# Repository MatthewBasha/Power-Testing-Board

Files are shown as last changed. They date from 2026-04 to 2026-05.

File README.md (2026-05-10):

# Power Testing Board

Compact CubeSat EPS ground power-test board for ATX/boost-supplied rails.

## Current Design State

- Root KiCad project: `Power Testing board.kicad_pro`
- Schematic was regenerated first in `Power Testing board.kicad_sch`.
- Serviceable PCB placement was generated in `Power Testing board.kicad_pcb`.
- Board outline is 230 mm x 170 mm.
- PCB is routed with rail-specific copper zones, a solid B.Cu GND plane, and final JLCPCB fabrication outputs in `fabrication/JLCPCB/`.

## Electrical Architecture

Each rail follows the required order:

`RAW input -> eFuse -> INA260 VIN+ -> INA260 VIN- -> protected output distribution`

Protected outputs then split to the dedicated output terminal and the selected EPS/H1/H2 power pins. The INA260 VIN- node is the downstream positive rail, not ground.

Rails:

- `+3V3_RAW -> TPS259814L -> U5 INA260 -> +3V3_PROTECTED`
- `+5V_RAW -> TPS26631RGE -> U6 INA260 -> +5V_PROTECTED`
- `+12V_RAW -> TPS26631RGE -> U7 INA260 -> +12V_PROTECTED`
- `+16V8_RAW -> TPS26631RGE -> U8 INA260 -> +16V8_PROTECTED`

## GitHub Portability

The project includes repo-local libraries so another computer can open it after cloning:

- `Power_Testing_Board.kicad_sym`
- `Power_Testing_Board.pretty/`
- `sym-lib-table`
- `fp-lib-table`

Keep those files committed with the KiCad project. Do not rely on absolute local library paths for the custom INA260 or boost module footprints.

## Verification Notes

- ERC: 0 errors, 11 warnings. Remaining warnings are isolated optional status labels such as PG, IMON, and ALERT.
- DRC: 0 violations, 0 unconnected items after routing and zone refill.
- Gerbers/drills are generated in `fabrication/JLCPCB/` after the clean DRC gate.
- Boost footprint is based on the supplied Amazon screenshots and has been physically verified: 60 mm x 42 mm x 20 mm.
- TPS259814L footprint is marked for package/land-pattern verification against the exact ordered part.
- eFuses are on the main PCB for compactness. If repairability becomes more important than board area, move each eFuse circuit to a plug-in daughterboard.
- Passive component purposes, design checks, test point map, and assembly notes are documented in `docs/passive_component_purpose_table.md`.

## Before Ordering

- Review the Gerber ZIP and drill files in JLCPCB/JLCDFM before purchase.
- Use 2 oz copper as documented in `fabrication/JLCPCB/README_ordering.md`.
- Verify ATX, EPS/H1/H2, output terminal, boost module, INA260 module, and eFuse footprints against the physical parts.
- Select/verify the LCSC or customer-supplied plan for all SMD BOM entries before placing the PCBA order.

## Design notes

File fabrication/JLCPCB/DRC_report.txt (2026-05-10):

** Drc report for Power Testing board.kicad_pcb **
** Created on 2026-05-10T00:28:49 **
** Report includes: Errors, Warnings **

** Found 0 DRC violations **

** Found 0 unconnected pads **

** Found 0 Footprint errors **

** Ignored checks **
    - Footprint has no courtyard defined
    - Track endpoint not centered on via
    - Tuning profile track geometries
    - Footprint doesn't match symbol's footprint filters
    - Footprint component type doesn't match footprint pads

** End of Report **

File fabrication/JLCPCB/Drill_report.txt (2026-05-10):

Drill report for Power Testing board.kicad_pcb
Created on 2026-05-10T00:29:23

Copper Layer Stackup:
    =============================================================
    L1 :  F.Cu                      front
    L2 :  B.Cu                      back

Drill file 'Power Testing board.drl' contains
    plated through holes:
    =============================================================
    T1  0.200mm  0.0079"  (27 holes))
    T2  0.300mm  0.0118"  (24 holes))
    T3  0.900mm  0.0354"  (2 holes))
    T4  1.000mm  0.0394"  (166 holes))
    T5  1.100mm  0.0433"  (24 holes))
    T6  1.300mm  0.0512"  (24 holes))
    T7  1.800mm  0.0709"  (4 holes))

    Total plated holes count 271

Not plated through holes are merged with plated holes
    unplated through holes:
    =============================================================
    T8  2.500mm  0.0984"  (8 holes))
    T9  3.200mm  0.1260"  (4 holes))

    Total unplated holes count 12

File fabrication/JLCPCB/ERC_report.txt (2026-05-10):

ERC report (2026-05-10T00:28:48, Encoding UTF8)
Report includes: Errors, Warnings

***** Sheet /
[isolated_pin_label]: Label connected to only one pin
    ; warning
    @(81.28 mm, 54.61 mm): Label 'PG_3V3'
[isolated_pin_label]: Label connected to only one pin
    ; warning
    @(83.82 mm, 119.38 mm): Label 'PG_5V'
[isolated_pin_label]: Label connected to only one pin
    ; warning
    @(83.82 mm, 124.46 mm): Label 'IMON_5V'
[isolated_pin_label]: Label connected to only one pin
    ; warning
    @(138.43 mm, 69.85 mm): Label 'ALERT_3V3'
[isolated_pin_label]: Label connected to only one pin
    ; warning
    @(138.43 mm, 129.54 mm): Label 'ALERT_5V'
[isolated_pin_label]: Label connected to only one pin
    ; warning
    @(83.82 mm, 179.07 mm): Label 'PG_12V'
[isolated_pin_label]: Label connected to only one pin
    ; warning
    @(83.82 mm, 184.15 mm): Label 'IMON_12V'
[isolated_pin_label]: Label connected to only one pin
    ; warning
    @(138.43 mm, 189.23 mm): Label 'ALERT_12V'
[isolated_pin_label]: Label connected to only one pin
    ; warning
    @(83.82 mm, 240.03 mm): Label 'PG_16V8'
[isolated_pin_label]: Label connected to only one pin
    ; warning
    @(83.82 mm, 245.11 mm): Label 'IMON_16V8'
[isolated_pin_label]: Label connected to only one pin
    ; warning
    @(138.43 mm, 250.19 mm): Label 'ALERT_16V8'

 ** ERC messages: 11  Errors 0  Warnings 11

 ** Ignored checks:
    - Global label only appears once in the schematic
    - Four connection points are joined together
    - SPICE model issue
    - Assigned footprint doesn't match footprint filters

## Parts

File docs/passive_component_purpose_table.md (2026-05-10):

# Passive Component Purpose Table

Generated for the root KiCad design in `E:\Power-Testing-Board`.

## Status Summary

- Resistors in schematic: R1-R34.
- Capacitors in schematic: C1-C8.
- Current-limit target remains about 6 A, not 8 A.
- No extra main-board I2C pullups are fitted. The Adafruit INA260 Product 4226 breakouts include 10 kOhm pullups on SDA and SCL, so four installed modules make an effective pullup of about 2.5 kOhm to `+ARDUINO_5V`.
- No main-board passive parts are added at the INA260 breakout headers; the INA260 boards are treated as complete plug-in modules.
- TPS26631 `dVdT`, `MODE`, `B_GATE`, `DRV`, `PGTH`, and `IMON` support parts are not populated in this design state. `MODE` is intentionally open for latch-off behavior per the project requirement.
- TPS26631 `SHDN` is controlled only by reset button/open-drain MOSFET pulldown. Released `SHDN` is acceptable because the TPS2663 datasheet specifies an internal open-circuit SHDN voltage and a 2 V rising enable threshold.
- TPS259814L `DVDT` and `ITIMER` are intentionally open for fastest startup and fastest overcurrent response unless a delay is intentionally added later.
- TPS259814L `PG` and TPS26631 `PGOOD`/`IMON` labels remain optional one-pin status nets. `FLT` is pulled up to Arduino 5 V and routed/test-pointed.

## Calculation Notes

- TPS259814L current limit: TI gives `RILM = 6585 / ILIM`; at 6 A this is 1097.5 Ohm, so R1 = 1.10 kOhm 1%.
- TPS26631 current limit: TI electrical characteristics list RILIM = 3 kOhm for a 6 A typical overload current limit.
- UVLO/OVLO/OVP dividers use the 1.20 V typical rising threshold: `Vtrip = 1.20 V * (Rtop + Rbottom) / Rbottom`.
- TPS26631 UVLO/OVP is implemented here as two independent dividers instead of the datasheet's combined three-resistor ladder. The threshold equation is the same comparator ratio form; the divider currents remain well above pin leakage.
- MOSFET gate resistors are engineering-standard damping/current-limiting values. Gate pulldowns are engineering-standard fail-off bias values.
- eFuse capacitor values are explicitly accepted starting values, not load-transient calculations. They satisfy local bypass intent, but final transient/load validation should confirm whether larger bulk capacitance or TVS/Schottky protection is needed.

## Capacitors

| Ref | Value | Footprint/package | Connected nets | Supports | Purpose | Required / optional / DNP | Datasheet section or design reason | Value source |
|---|---:|---|---|---|---|---|---|---|
| C1 | 1 uF 25 V X7R | C_0805_2012Metric | `+3V3_RAW` to `GND` | U1 TPS259814L | Local input bypass at 3.3 V eFuse input. | Required | TPS25981 power-supply/transient guidance: local input ceramic bypass close to IN/GND. | Accepted starting value; voltage rating selected with margin. |
| C2 | 10 uF 25 V X7R | C_0805_2012Metric | `+3V3_EFUSE_OUT` to `GND` | U1 TPS259814L and U5 INA260 input side | Local OUT-side capacitance before the INA260 module. | Required | TPS25981 transient guidance calls for low-ESR capacitance close to OUT/GND for output transients. | Accepted starting value; verify with load transient testing. |
| C3 | 1 uF 25 V X7R | C_0805_2012Metric | `+5V_RAW` to `GND` | U2 TPS26631 | Local input bypass at 5 V eFuse input. | Required | TPS2663 recommends at least 0.1 uF IN_SYS-GND decoupling and at least 1 uF input capacitance for transient-prone applications. | Copied/accepted from TI guidance. |
| C4 | 10 uF 25 V X7R | C_0805_2012Metric | `+5V_EFUSE_OUT` to `GND` | U2 TPS26631 and U6 INA260 input side | Local OUT-side/load-side capacitance before the INA260 module. | Required | TPS2663 application figures include output capacitance; exact value depends on load/inrush. | Accepted starting value; verify inrush/transient behavior. |
| C5 | 1 uF 50 V X7R | C_0805_2012Metric | `+12V_RAW` to `GND` | U3 TPS26631 | Local input bypass at 12 V eFuse input. | Required | TPS2663 decoupling/transient guidance. | Copied/accepted from TI guidance; 50 V rating for derating. |
| C6 | 10 uF 50 V X7R | C_0805_2012Metric | `+12V_EFUSE_OUT` to `GND` | U3 TPS26631 and U7 INA260 input side | Local OUT-side/load-side capacitance before the INA260 module. | Required | TPS2663 application/output capacitance guidance. | Accepted starting value; verify inrush/transient behavior. |
| C7 | 1 uF 50 V X7R | C_0805_2012Metric | `+16V8_RAW` to `GND` | U4 TPS26631 | Local input bypass at 16.8 V eFuse input. | Required | TPS2663 decoupling/transient guidance. | Copied/accepted from TI guidance; 50 V rating for derating. |
| C8 | 10 uF 50 V X7R | C_0805_2012Metric | `+16V8_EFUSE_OUT` to `GND` | U4 TPS26631 and U8 INA260 input side | Local OUT-side/load-side capacitance before the INA260 module. | Required | TPS2663 application/output capacitance guidance. | Accepted starting value; verify inrush/transient behavior. |

## Resistors

| Ref | Value | Footprint/package | Connected nets | Supports | Purpose | Required / optional / DNP | Datasheet section or design reason | Value source |
|---|---:|---|---|---|---|---|---|---|
| R1 | 1.10 kOhm 1% | R_0805_2012Metric | `ILIM_3V3` to `GND` | U1 TPS259814L | Sets 3.3 V eFuse current limit near 6 A. | Required | TPS25981 ILM equation `RILM = 6585 / ILIM`. | Calculated: 6585 / 6 A = 1097.5 Ohm. |
| R2 | 100 kOhm 1% | R_0603_1608Metric | `+3V3_RAW` to `RESET_3V3` | U1 EN/UVLO | Top of EN/UVLO divider; normally enables U1. | Required | TPS25981 EN/UVLO divider equation. | Calculated/selected: with R3 gives 2.40 V rising UVLO. |
| R3 | 100 kOhm 1% | R_0603_1608Metric | `RESET_3V3` to `GND` | U1 EN/UVLO | Bottom of EN/UVLO divider and reset node bias. | Required | TPS25981 EN/UVLO divider equation. | Calculated/selected with R2. |
| R4 | 24.9 kOhm 1% | R_0603_1608Metric | `+3V3_RAW` to `OVLO_3V3` | U1 EN/OVLO | Top of 3.3 V OVLO divider. | Required | TPS25981 EN/OVLO divider equation. | Calculated: with R5 gives 4.19 V rising OVLO. |
| R5 | 10 kOhm 1% | R_0603_1608Metric | `OVLO_3V3` to `GND` | U1 EN/OVLO | Bottom of 3.3 V OVLO divider. | Required | TPS25981 EN/OVLO divider equation. | Calculated/selected with R4. |
| R6 | 330 Ohm | R_0603_1608Metric | `ARD_RESET_3V3` to `GATE_3V3` | Q1 / U1 reset | Arduino GPIO series gate resistor. | Required if Arduino reset is populated | Limits instantaneous GPIO/gate current and damps ringing. | Justified engineering-standard value. |
| R7 | 100 kOhm | R_0603_1608Metric | `GATE_3V3` to `GND` | Q1 / U1 reset | Holds reset MOSFET off while Arduino resets/unpowered. | Required | Fail-off MOSFET gate bias. | Justified engineering-standard value. |
| R8 | 10 kOhm | R_0603_1608Metric | `FLT_3V3` to `+ARDUINO_5V` | U1 FLT | Pulls open-drain fault output to Arduino logic. | Required if FLT is used; DNP if unused | TPS25981 FLT is open-drain; 10 kOhm gives about 0.5 mA sink at 5 V. | Justified/calculated pullup value. |
| R9 | 3.00 kOhm 1% | R_0805_2012Metric | `ILIM_5V` to `GND` | U2 TPS26631 | Sets 5 V current limit near 6 A. | Required | TPS2663 current-limit table: 3 kOhm gives 6 A typical. | Copied from datasheet/user requirement. |
| R10 | 261 kOhm 1% | R_0603_1608Metric | `+5V_RAW` to `UVLO_5V` | U2 UVLO | Top of 5 V UVLO divider. | Required | TPS2663 UVLO threshold 1.20 V typical. | Calculated: with R11 gives 4.33 V rising UVLO. |
| R11 | 100 kOhm 1% | R_0603_1608Metric | `UVLO_5V` to `GND` | U2 UVLO | Bottom of 5 V UVLO divider. | Required | TPS2663 UVLO divider design. | Calculated/selected with R10. |
| R12 | 383 kOhm 1% | R_0603_1608Metric | `+5V_RAW` to `OVP_5V` | U2 OVP | Top of 5 V OVP divider. | Required | TPS2663 OVP threshold 1.20 V typical. | Calculated: with R13 gives 5.80 V rising OVP. |
| R13 | 100 kOhm 1% | R_0603_1608Metric | `OVP_5V` to `GND` | U2 OVP | Bottom of 5 V OVP divider. | Required | TPS2663 OVP divider design. | Calculated/selected with R12. |
| R14 | 330 Ohm | R_0603_1608Metric | `ARD_RESET_5V` to `GATE_5V` | Q2 / U2 SHDN | Arduino GPIO series gate resistor. | Required if Arduino reset is populated | GPIO/gate damping and current limiting. | Justified engineering-standard value. |
| R15 | 100 kOhm | R_0603_1608Metric | `GATE_5V` to `GND` | Q2 / U2 SHDN | Holds reset MOSFET off while Arduino resets/unpowered. | Required | Fail-off MOSFET gate bias. | Justified engineering-standard value. |
| R16 | 10 kOhm | R_0603_1608Metric | `FLT_5V` to `+ARDUINO_5V` | U2 FLT | Pulls open-drain fault output to Arduino logic. | Required if FLT is used; DNP if unused | TPS2663 FLT is open-drain and may be left open if unused. | Justified/calculated: about 0.5 mA when asserted. |
| R17 | 3.00 kOhm 1% | R_0805_2012Metric | `ILIM_12V` to `GND` | U3 TPS26631 | Sets 12 V current limit near 6 A. | Required | TPS2663 current-limit table. | Copied from datasheet/user requirement. |
| R18 | 806 kOhm 1% | R_0603_1608Metric | `+12V_RAW` to `UVLO_12V` | U3 UVLO | Top of 12 V UVLO divider. | Required | TPS2663 UVLO threshold 1.20 V typical. | Calculated: with R19 gives 10.87 V rising UVLO. |
| R19 | 100 kOhm 1% | R_0603_1608Metric | `UVLO_12V` to `GND` | U3 UVLO | Bottom of 12 V UVLO divider. | Required | TPS2663 UVLO divider design. | Calculated/selected with R18. |
| R20 | 1.05 MOhm 1% | R_0603_1608Metric | `+12V_RAW` to `OVP_12V` | U3 OVP | Top of 12 V OVP divider. | Required | TPS2663 OVP threshold 1.20 V typical. | Calculated: with R21 gives 13.80 V rising OVP. |
| R21 | 100 kOhm 1% | R_0603_1608Metric | `OVP_12V` to `GND` | U3 OVP | Bottom of 12 V OVP divider. | Required | TPS2663 OVP divider design. | Calculated/selected with R20. |
| R22 | 330 Ohm | R_0603_1608Metric | `ARD_RESET_12V` to `GATE_12V` | Q3 / U3 SHDN | Arduino GPIO series gate resistor. | Required if Arduino reset is populated | GPIO/gate damping and current limiting. | Justified engineering-standard value. |
| R23 | 100 kOhm | R_0603_1608Metric | `GATE_12V` to `GND` | Q3 / U3 SHDN | Holds reset MOSFET off while Arduino resets/unpowered. | Required | Fail-off MOSFET gate bias. | Justified engineering-standard value. |
| R24 | 10 kOhm | R_0603_1608Metric | `FLT_12V` to `+ARDUINO_5V` | U3 FLT | Pulls open-drain fault output to Arduino logic. | Required if FLT is used; DNP if unused | TPS2663 FLT open-drain use. | Justified/calculated: about 0.5 mA when asserted. |
| R25 | 3.00 kOhm 1% | R_0805_2012Metric | `ILIM_16V8` to `GND` | U4 TPS26631 | Sets 16.8 V current limit near 6 A. | Required | TPS2663 current-limit table. | Copied from datasheet/user requirement. |
| R26 | 1.07 MOhm 1% | R_0603_1608Metric | `+16V8_RAW` to `UVLO_16V8` | U4 UVLO | Top of 16.8 V UVLO divider. | Required | TPS2663 UVLO threshold 1.20 V typical. | Calculated: with R27 gives 14.04 V rising UVLO. |
| R27 | 100 kOhm 1% | R_0603_1608Metric | `UVLO_16V8` to `GND` | U4 UVLO | Bottom of 16.8 V UVLO divider. | Required | TPS2663 UVLO divider design. | Calculated/selected with R26. |
| R28 | 1.40 MOhm 1% | R_0603_1608Metric | `+16V8_RAW` to `OVP_16V8` | U4 OVP | Top of 16.8 V OVP divider. | Required | TPS2663 OVP threshold 1.20 V typical. | Calculated: with R29 gives 18.00 V rising OVP. |
| R29 | 100 kOhm 1% | R_0603_1608Metric | `OVP_16V8` to `GND` | U4 OVP | Bottom of 16.8 V OVP divider. | Required | TPS2663 OVP divider design. | Calculated/selected with R28. |
| R30 | 330 Ohm | R_0603_1608Metric | `ARD_RESET_16V8` to `GATE_16V8` | Q4 / U4 SHDN | Arduino GPIO series gate resistor. | Required if Arduino reset is populated | GPIO/gate damping and current limiting. | Justified engineering-standard value. |
| R31 | 100 kOhm | R_0603_1608Metric | `GATE_16V8` to `GND` | Q4 / U4 SHDN | Holds reset MOSFET off while Arduino resets/unpowered. | Required | Fail-off MOSFET gate bias. | Justified engineering-standard value. |
| R32 | 10 kOhm | R_0603_1608Metric | `FLT_16V8` to `+ARDUINO_5V` | U4 FLT | Pulls open-drain fault output to Arduino logic. | Required if FLT is used; DNP if unused | TPS2663 FLT open-drain use. | Justified/calculated: about 0.5 mA when asserted. |
| R33 | 330 Ohm | R_0603_1608Metric | `ATX_PS_ON_CTL` to `GATE_PS_ON` | Q5 ATX PS_ON# | Arduino GPIO series gate resistor. | Required if Arduino PS_ON control is populated | GPIO/gate damping and current limiting. | Justified engineering-standard value. |
| R34 | 100 kOhm | R_0603_1608Metric | `GATE_PS_ON` to `GND` | Q5 ATX PS_ON# | Holds ATX PS_ON MOSFET off while Arduino resets/unpowered. | Required | Fail-off MOSFET gate bias. | Justified engineering-standard value. |

## Design Checks Before Routing/Fabrication

| Check | Result |
|---|---|
| Rail order on every rail | Confirmed in schematic/PCB net assignment: RAW -> eFuse -> INA260 VIN+ -> INA260 VIN- -> protected node. |
| eFuse before INA260 | Confirmed for +3.3 V, +5 V, +12 V, and +16.8 V. |
| INA260 measures protected load power | Confirmed: dedicated outputs and EPS/header pins use only the `+RAIL_PROTECTED` nets after INA260 VIN-. |
| INA260 VIN- never tied to GND | Confirmed: U5-U8 pad 8 nets are `+3V3_PROTECTED`, `+5V_PROTECTED`, `+12V_PROTECTED`, and `+16V8_PROTECTED`. |
| Dedicated output and EPS/header included in measurement | Confirmed: J4 and H1/H2 selected power pins branch from protected post-INA260 nets. |
| Common ground | Confirmed by shared `GND` net for ATX, Arduino, INA260 modules, eFuses, boost module, and outputs. |
| Current-limit target | Confirmed near 6 A by R1/R9/R17/R25; board copper/connectors still need 8 A to 10 A routing margin. |
| ATX input connector style | Confirmed screw terminals J1/J2, not a 24-pin ATX motherboard connector. |
| ATX PS_ON# control | Confirmed: green-wire `ATX_PS_ON_N` enters J2, external switch J3 shorts it to GND, Arduino pulls low through Q5 only. |
| Reset buttons | Confirmed SW1-SW4 are momentary through-hole buttons on an edge row, pulling each reset/control node low. |
| Arduino Nano orientation | Confirmed: A1 uses `Module:Arduino_Nano`, is header-mounted, rotated 90 degrees; USB is intended to face the left board edge. |
| Modularity | Confirmed for Arduino headers, INA260 module headers, verified boost module footprint, ATX terminals, output terminals, EPS headers, and through-hole buttons. |
| SMD eFuse serviceability | Manufacturer-assembled SMD; placed on main PCB with nearby passives/test points, not hidden under plug-in modules. |
| High-current layout | Not complete. Must be routed with wide pours/traces, 2 oz copper preferred, via arrays for layer changes, solid GND plane, short eFuse-to-INA260 current path, and thermal via stitching. |
| Test points | Confirmed TP1-TP29 cover requested rail states, GND, I2C, ATX control/status, reset, FLT, and boost input/output/GND. |
| Connector footprints | Present for ATX screw terminals, verified boost module, Adafruit INA260 modules, Arduino Nano, dedicated outputs, H1/H2 EPS headers, and reset buttons. Final physical current-rating review still required. |

## Test Point Map

| Net/function | Test point |
|---|---|
| `+3V3_RAW` | TP1 |
| `+3V3_EFUSE_OUT` | TP2 |
| `+3V3_PROTECTED` | TP3 |
| `+5V_RAW` | TP4 |
| `+5V_EFUSE_OUT` | TP5 |
| `+5V_PROTECTED` | TP6 |
| `+12V_RAW` | TP7 |
| `+12V_EFUSE_OUT` | TP8 |
| `+12V_PROTECTED` | TP9 |
| `+16V8_RAW` | TP10 |
| `+16V8_EFUSE_OUT` | TP11 |
| `+16V8_PROTECTED` | TP12 |
| `GND` | TP13 |
| `I2C_SDA` | TP14 |
| `I2C_SCL` | TP15 |
| `ATX_PS_ON_N` | TP16 |
| `ATX_PWR_OK` | TP17 |
| `+5VSB` | TP18 |
| `RESET_3V3` | TP19 |
| `RESET_5V` | TP20 |
| `RESET_12V` | TP21 |
| `RESET_16V8` | TP22 |
| `FLT_3V3` | TP23 |
| `FLT_5V` | TP24 |
| `FLT_12V` | TP25 |
| `FLT_16V8` | TP26 |
| `BOOST_IN+` / `+12V_RAW` | TP27 |
| `BOOST_OUT+` / `+16V8_RAW` | TP28 |
| `BOOST_GND` | TP29 |

## Current ERC/DRC Status

- ERC: 0 errors, 11 warnings. Warnings are isolated optional labels for PG, IMON, and ALERT signals.
- DRC: 0 violations, 0 unconnected items after routing and copper-zone refill.
- Routing gate: passed. Final Gerbers/drills were generated after the clean DRC gate.

## Source References

- TI TPS2663 datasheet/product page: https://www.ti.com/lit/gpn/TPS2663
- TI TPS25981 datasheet: https://www.ti.com/lit/ds/symlink/tps25981.pdf
- Adafruit INA260 Product 4226: https://www.adafruit.com/product/4226
- Adafruit INA260 pinouts and onboard I2C pullups: https://learn.adafruit.com/adafruit-ina260-current-voltage-power-sensor-breakout/pinouts

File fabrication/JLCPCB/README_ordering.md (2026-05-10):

# JLCPCB Ordering README

Status: ready for fabrication-file review.

## Current gate

- Gerber ZIP: generated after DRC clean.
- Drill files: generated after DRC clean.
- KiCad DRC: 0 violations, 0 unconnected items.
- Use JLCPCB/JLCDFM preview to verify board outline, drills, solder mask, and assembly rotations before purchase.

## Recommended order settings after DRC is clean

- PCB type: FR-4, 2 layers unless routing requires a 4-layer revision.
- Board thickness: 1.6 mm.
- Copper weight: 2 oz outer copper preferred for high-current margin. Confirm current availability/pricing on the JLCPCB order page.
- Solder mask: green preferred for lowest process risk unless the team wants a different color.
- Surface finish: ENIG preferred for the fine-pitch QFN/eFuse footprints and flatter pads; lead-free HASL is acceptable only after confirming pad planarity/rework tradeoffs.
- Assembly side: top side only for the SMD manufacturer-assembled parts.
- Manual parts: exclude headers, modules, screw terminals, EPS connectors, and reset buttons from the JLCPCB SMD BOM/CPL unless the team explicitly decides otherwise.

## JLCPCB file-prep reminders

- BOM and CPL designators must match exactly.
- Use millimeters in the CPL.
- Check every SMD rotation in JLCPCB preview, especially U1-U4 and Q1-Q5.
- Replace all `CUSTOMER_SUPPLIED_OR_SELECT_LCSC` / `CUSTOMER_SUPPLIED_OR_VERIFY_LCSC` placeholders with real selected parts or a JLCPCB customer-supplied-parts plan before ordering.

Sources checked:

- JLCPCB copper weight guide: https://jlcpcb.com/help/article/jlcpcb-copper-weight
- JLCPCB surface finish guide: https://jlcpcb.com/help/article/jlcpcb-surface-finish
- JLCPCB BOM/CPL preparation guidance: https://jlcpcb.com/help/article/advice-for-bom-and-cpl-files-preparation

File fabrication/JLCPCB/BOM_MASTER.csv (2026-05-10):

Designator | Value | Footprint | Category | Install responsibility | LCSC Part # | Manufacturer Part # / Notes
A1 | Arduino Nano USB-powered socket | Arduino_Nano | Manual/serviceable | Install manually after PCBA | N/A | Arduino Nano USB-powered socket
C1 | 1uF 25V X7R input close to eFuse | C_0805_2012Metric | SMD manufacturer-assembled | JLCPCB | CUSTOMER_SUPPLIED_OR_SELECT_LCSC | Generic passive; select voltage/tolerance/package in JLC parts library
C2 | 10uF 25V X7R output close to eFuse | C_0805_2012Metric | SMD manufacturer-assembled | JLCPCB | CUSTOMER_SUPPLIED_OR_SELECT_LCSC | Generic passive; select voltage/tolerance/package in JLC parts library
C3 | 1uF 25V X7R input close to eFuse | C_0805_2012Metric | SMD manufacturer-assembled | JLCPCB | CUSTOMER_SUPPLIED_OR_SELECT_LCSC | Generic passive; select voltage/tolerance/package in JLC parts library
C4 | 10uF 25V X7R output close to eFuse | C_0805_2012Metric | SMD manufacturer-assembled | JLCPCB | CUSTOMER_SUPPLIED_OR_SELECT_LCSC | Generic passive; select voltage/tolerance/package in JLC parts library
C5 | 1uF 50V X7R input close to eFuse | C_0805_2012Metric | SMD manufacturer-assembled | JLCPCB | CUSTOMER_SUPPLIED_OR_SELECT_LCSC | Generic passive; select voltage/tolerance/package in JLC parts library
C6 | 10uF 50V X7R output close to eFuse | C_0805_2012Metric | SMD manufacturer-assembled | JLCPCB | CUSTOMER_SUPPLIED_OR_SELECT_LCSC | Generic passive; select voltage/tolerance/package in JLC parts library
C7 | 1uF 50V X7R input close to eFuse | C_0805_2012Metric | SMD manufacturer-assembled | JLCPCB | CUSTOMER_SUPPLIED_OR_SELECT_LCSC | Generic passive; select voltage/tolerance/package in JLC parts library
C8 | 10uF 50V X7R output close to eFuse | C_0805_2012Metric | SMD manufacturer-assembled | JLCPCB | CUSTOMER_SUPPLIED_OR_SELECT_LCSC | Generic passive; select voltage/tolerance/package in JLC parts library
J1 | J_ATX_PWR: 3V3 3V3 5V 5V 12V 12V GNDx4 | TerminalBlock_MaiXu_MX126-5.0-10P_1x10_P5.00mm | Manual/serviceable | Install manually after PCBA | N/A | J_ATX_PWR: 3V3 3V3 5V 5V 12V 12V GNDx4
J2 | J_ATX_CTRL: PS_ON PWR_OK 5VSB GND | TerminalBlock_MaiXu_MX126-5.0-04P_1x04_P5.00mm | Manual/serviceable | Install manually after PCBA | N/A | J_ATX_CTRL: PS_ON PWR_OK 5VSB GND
J3 | ATX_SWITCH | TerminalBlock_MaiXu_MX126-5.0-02P_1x02_P5.00mm | Manual/serviceable | Install manually after PCBA | N/A | ATX_SWITCH
J4 | DEDICATED OUTPUTS: 3V3/G 5V/G 12V/G 16V8/G | TerminalBlock_MaiXu_MX126-5.0-08P_1x08_P5.00mm | Manual/serviceable | Install manually after PCBA | N/A | DEDICATED OUTPUTS: 3V3/G 5V/G 12V/G 16V8/G
JH1 | H1 selected power/GND pins only | PinSocket_2x26_P2.54mm_Vertical | Manual/serviceable | Install manually after PCBA | N/A | H1 selected power/GND pins only
JH2 | H2 selected power/GND pins only | PinSocket_2x26_P2.54mm_Vertical | Manual/serviceable | Install manually after PCBA | N/A | H2 selected power/GND pins only
Q1 | 2N7002 RESET_3V3 pulldown | SOT-23 | SMD manufacturer-assembled | JLCPCB | CUSTOMER_SUPPLIED_OR_SELECT_LCSC | 2N7002 SOT-23, select JLC basic/extended part before order
Q2 | 2N7002 RESET_5V pulldown | SOT-23 | SMD manufacturer-assembled | JLCPCB | CUSTOMER_SUPPLIED_OR_SELECT_LCSC | 2N7002 SOT-23, select JLC basic/extended part before order
Q3 | 2N7002 RESET_12V pulldown | SOT-23 | SMD manufacturer-assembled | JLCPCB | CUSTOMER_SUPPLIED_OR_SELECT_LCSC | 2N7002 SOT-23, select JLC basic/extended part before order
Q4 | 2N7002 RESET_16V8 pulldown | SOT-23 | SMD manufacturer-assembled | JLCPCB | CUSTOMER_SUPPLIED_OR_SELECT_LCSC | 2N7002 SOT-23, select JLC basic/extended part before order
Q5 | 2N7002 ATX PS_ON# pulldown | SOT-23 | SMD manufacturer-assembled | JLCPCB | CUSTOMER_SUPPLIED_OR_SELECT_LCSC | 2N7002 SOT-23, select JLC basic/extended part before order
R1 | 1.10k 1% ILM ~6A | R_0805_2012Metric | SMD manufacturer-assembled | JLCPCB | CUSTOMER_SUPPLIED_OR_SELECT_LCSC | Generic passive; select voltage/tolerance/package in JLC parts library
R2 | 100k 1% EN top 2.40V | R_0603_1608Metric | SMD manufacturer-assembled | JLCPCB | CUSTOMER_SUPPLIED_OR_SELECT_LCSC | Generic passive; select voltage/tolerance/package in JLC parts library
R3 | 100k 1% EN bottom | R_0603_1608Metric | SMD manufacturer-assembled | JLCPCB | CUSTOMER_SUPPLIED_OR_SELECT_LCSC | Generic passive; select voltage/tolerance/package in JLC parts library
R4 | 24.9k 1% OVLO top 4.19V | R_0603_1608Metric | SMD manufacturer-assembled | JLCPCB | CUSTOMER_SUPPLIED_OR_SELECT_LCSC | Generic passive; select voltage/tolerance/package in JLC parts library
R5 | 10k 1% OVLO bottom | R_0603_1608Metric | SMD manufacturer-assembled | JLCPCB | CUSTOMER_SUPPLIED_OR_SELECT_LCSC | Generic passive; select voltage/tolerance/package in JLC parts library
R6 | 330 gate | R_0603_1608Metric | SMD manufacturer-assembled | JLCPCB | CUSTOMER_SUPPLIED_OR_SELECT_LCSC | Generic passive; select voltage/tolerance/package in JLC parts library
R7 | 100k gate pulldown | R_0603_1608Metric | SMD manufacturer-assembled | JLCPCB | CUSTOMER_SUPPLIED_OR_SELECT_LCSC | Generic passive; select voltage/tolerance/package in JLC parts library
R8 | 10k FLT pullup | R_0603_1608Metric | SMD manufacturer-assembled | JLCPCB | CUSTOMER_SUPPLIED_OR_SELECT_LCSC | Generic passive; select voltage/tolerance/package in JLC parts library
R9 | 3.00k 1% ILIM ~6A | R_0805_2012Metric | SMD manufacturer-assembled | JLCPCB | CUSTOMER_SUPPLIED_OR_SELECT_LCSC | Generic passive; select voltage/tolerance/package in JLC parts library
R10 | 261k 1% UVLO top 4.33V | R_0603_1608Metric | SMD manufacturer-assembled | JLCPCB | CUSTOMER_SUPPLIED_OR_SELECT_LCSC | Generic passive; select voltage/tolerance/package in JLC parts library
R11 | 100k 1% UVLO bottom | R_0603_1608Metric | SMD manufacturer-assembled | JLCPCB | CUSTOMER_SUPPLIED_OR_SELECT_LCSC | Generic passive; select voltage/tolerance/package in JLC parts library
R12 | 383k 1% OVP top 5.80V | R_0603_1608Metric | SMD manufacturer-assembled | JLCPCB | CUSTOMER_SUPPLIED_OR_SELECT_LCSC | Generic passive; select voltage/tolerance/package in JLC parts library
R13 | 100k 1% OVP bottom | R_0603_1608Metric | SMD manufacturer-assembled | JLCPCB | CUSTOMER_SUPPLIED_OR_SELECT_LCSC | Generic passive; select voltage/tolerance/package in JLC parts library
R14 | 330 gate | R_0603_1608Metric | SMD manufacturer-assembled | JLCPCB | CUSTOMER_SUPPLIED_OR_SELECT_LCSC | Generic passive; select voltage/tolerance/package in JLC parts library
R15 | 100k gate pulldown | R_0603_1608Metric | SMD manufacturer-assembled | JLCPCB | CUSTOMER_SUPPLIED_OR_SELECT_LCSC | Generic passive; select voltage/tolerance/package in JLC parts library
R16 | 10k FLT pullup | R_0603_1608Metric | SMD manufacturer-assembled | JLCPCB | CUSTOMER_SUPPLIED_OR_SELECT_LCSC | Generic passive; select voltage/tolerance/package in JLC parts library
R17 | 3.00k 1% ILIM ~6A | R_0805_2012Metric | SMD manufacturer-assembled | JLCPCB | CUSTOMER_SUPPLIED_OR_SELECT_LCSC | Generic passive; select voltage/tolerance/package in JLC parts library
R18 | 806k 1% UVLO top 10.87V | R_0603_1608Metric | SMD manufacturer-assembled | JLCPCB | CUSTOMER_SUPPLIED_OR_SELECT_LCSC | Generic passive; select voltage/tolerance/package in JLC parts library
R19 | 100k 1% UVLO bottom | R_0603_1608Metric | SMD manufacturer-assembled | JLCPCB | CUSTOMER_SUPPLIED_OR_SELECT_LCSC | Generic passive; select voltage/tolerance/package in JLC parts library
R20 | 1.05M 1% OVP top 13.80V | R_0603_1608Metric | SMD manufacturer-assembled | JLCPCB | CUSTOMER_SUPPLIED_OR_SELECT_LCSC | Generic passive; select voltage/tolerance/package in JLC parts library
R21 | 100k 1% OVP bottom | R_0603_1608Metric | SMD manufacturer-assembled | JLCPCB | CUSTOMER_SUPPLIED_OR_SELECT_LCSC | Generic passive; select voltage/tolerance/package in JLC parts library
R22 | 330 gate | R_0603_1608Metric | SMD manufacturer-assembled | JLCPCB | CUSTOMER_SUPPLIED_OR_SELECT_LCSC | Generic passive; select voltage/tolerance/package in JLC parts library
R23 | 100k gate pulldown | R_0603_1608Metric | SMD manufacturer-assembled | JLCPCB | CUSTOMER_SUPPLIED_OR_SELECT_LCSC | Generic passive; select voltage/tolerance/package in JLC parts library
R24 | 10k FLT pullup | R_0603_1608Metric | SMD manufacturer-assembled | JLCPCB | CUSTOMER_SUPPLIED_OR_SELECT_LCSC | Generic passive; select voltage/tolerance/package in JLC parts library
R25 | 3.00k 1% ILIM ~6A | R_0805_2012Metric | SMD manufacturer-assembled | JLCPCB | CUSTOMER_SUPPLIED_OR_SELECT_LCSC | Generic passive; select voltage/tolerance/package in JLC parts library
R26 | 1.07M 1% UVLO top 14.04V | R_0603_1608Metric | SMD manufacturer-assembled | JLCPCB | CUSTOMER_SUPPLIED_OR_SELECT_LCSC | Generic passive; select voltage/tolerance/package in JLC parts library
R27 | 100k 1% UVLO bottom | R_0603_1608Metric | SMD manufacturer-assembled | JLCPCB | CUSTOMER_SUPPLIED_OR_SELECT_LCSC | Generic passive; select voltage/tolerance/package in JLC parts library
R28 | 1.40M 1% OVP top 18.00V | R_0603_1608Metric | SMD manufacturer-assembled | JLCPCB | CUSTOMER_SUPPLIED_OR_SELECT_LCSC | Generic passive; select voltage/tolerance/package in JLC parts library
R29 | 100k 1% OVP bottom | R_0603_1608Metric | SMD manufacturer-assembled | JLCPCB | CUSTOMER_SUPPLIED_OR_SELECT_LCSC | Generic passive; select voltage/tolerance/package in JLC parts library
R30 | 330 gate | R_0603_1608Metric | SMD manufacturer-assembled | JLCPCB | CUSTOMER_SUPPLIED_OR_SELECT_LCSC | Generic passive; select voltage/tolerance/package in JLC parts library
R31 | 100k gate pulldown | R_0603_1608Metric | SMD manufacturer-assembled | JLCPCB | CUSTOMER_SUPPLIED_OR_SELECT_LCSC | Generic passive; select voltage/tolerance/package in JLC parts library
R32 | 10k FLT pullup | R_0603_1608Metric | SMD manufacturer-assembled | JLCPCB | CUSTOMER_SUPPLIED_OR_SELECT_LCSC | Generic passive; select voltage/tolerance/package in JLC parts library
R33 | 330 gate | R_0603_1608Metric | SMD manufacturer-assembled | JLCPCB | CUSTOMER_SUPPLIED_OR_SELECT_LCSC | Generic passive; select voltage/tolerance/package in JLC parts library
R34 | 100k gate pulldown | R_0603_1608Metric | SMD manufacturer-assembled | JLCPCB | CUSTOMER_SUPPLIED_OR_SELECT_LCSC | Generic passive; select voltage/tolerance/package in JLC parts library
SW1 | RESET_3V3 edge button | SW_PUSH_6mm | Manual/serviceable | Install manually after PCBA | N/A | RESET_3V3 edge button
SW2 | RESET_5V edge button | SW_PUSH_6mm | Manual/serviceable | Install manually after PCBA | N/A | RESET_5V edge button
SW3 | RESET_12V edge button | SW_PUSH_6mm | Manual/serviceable | Install manually after PCBA | N/A | RESET_12V edge button
SW4 | RESET_16V8 edge button | SW_PUSH_6mm | Manual/serviceable | Install manually after PCBA | N/A | RESET_16V8 edge button
TP1 | +3V3_RAW | TestPoint_Pad_D1.0mm | PCB feature / no install | Not installed | N/A | +3V3_RAW
TP2 | +3V3_EFUSE_OUT | TestPoint_Pad_D1.0mm | PCB feature / no install | Not installed | N/A | +3V3_EFUSE_OUT
TP3 | +3V3_PROTECTED | TestPoint_Pad_D1.0mm | PCB feature / no install | Not installed | N/A | +3V3_PROTECTED
TP4 | +5V_RAW | TestPoint_Pad_D1.0mm | PCB feature / no install | Not installed | N/A | +5V_RAW
TP5 | +5V_EFUSE_OUT | TestPoint_Pad_D1.0mm | PCB feature / no install | Not installed | N/A | +5V_EFUSE_OUT
TP6 | +5V_PROTECTED | TestPoint_Pad_D1.0mm | PCB feature / no install | Not installed | N/A | +5V_PROTECTED
TP7 | +12V_RAW | TestPoint_Pad_D1.0mm | PCB feature / no install | Not installed | N/A | +12V_RAW
TP8 | +12V_EFUSE_OUT | TestPoint_Pad_D1.0mm | PCB feature / no install | Not installed | N/A | +12V_EFUSE_OUT
TP9 | +12V_PROTECTED | TestPoint_Pad_D1.0mm | PCB feature / no install | Not installed | N/A | +12V_PROTECTED
TP10 | +16V8_RAW | TestPoint_Pad_D1.0mm | PCB feature / no install | Not installed | N/A | +16V8_RAW
TP11 | +16V8_EFUSE_OUT | TestPoint_Pad_D1.0mm | PCB feature / no install | Not installed | N/A | +16V8_EFUSE_OUT
TP12 | +16V8_PROTECTED | TestPoint_Pad_D1.0mm | PCB feature / no install | Not installed | N/A | +16V8_PROTECTED
TP13 | GND | TestPoint_Pad_D1.0mm | PCB feature / no install | Not installed | N/A | GND
TP14 | I2C_SDA | TestPoint_Pad_D1.0mm | PCB feature / no install | Not installed | N/A | I2C_SDA
TP15 | I2C_SCL | TestPoint_Pad_D1.0mm | PCB feature / no install | Not installed | N/A | I2C_SCL
TP16 | ATX_PS_ON_N | TestPoint_Pad_D1.0mm | PCB feature / no install | Not installed | N/A | ATX_PS_ON_N
TP17 | ATX_PWR_OK | TestPoint_Pad_D1.0mm | PCB feature / no install | Not installed | N/A | ATX_PWR_OK
TP18 | +5VSB | TestPoint_Pad_D1.0mm | PCB feature / no install | Not installed | N/A | +5VSB
TP19 | RESET_3V3 | TestPoint_Pad_D1.0mm | PCB feature / no install | Not installed | N/A | RESET_3V3
TP20 | RESET_5V | TestPoint_Pad_D1.0mm | PCB feature / no install | Not installed | N/A | RESET_5V
TP21 | RESET_12V | TestPoint_Pad_D1.0mm | PCB feature / no install | Not installed | N/A | RESET_12V
TP22 | RESET_16V8 | TestPoint_Pad_D1.0mm | PCB feature / no install | Not installed | N/A | RESET_16V8
TP23 | FLT_3V3 | TestPoint_Pad_D1.0mm | PCB feature / no install | Not installed | N/A | FLT_3V3
TP24 | FLT_5V | TestPoint_Pad_D1.0mm | PCB feature / no install | Not installed | N/A | FLT_5V
TP25 | FLT_12V | TestPoint_Pad_D1.0mm | PCB feature / no install | Not installed | N/A | FLT_12V
TP26 | FLT_16V8 | TestPoint_Pad_D1.0mm | PCB feature / no install | Not installed | N/A | FLT_16V8
TP27 | BOOST_IN+ (+12V_RAW) | TestPoint_Pad_D1.0mm | PCB feature / no install | Not installed | N/A | BOOST_IN+ (+12V_RAW)
TP28 | BOOST_OUT+ (+16V8_RAW) | TestPoint_Pad_D1.0mm | PCB feature / no install | Not installed | N/A | BOOST_OUT+ (+16V8_RAW)
TP29 | BOOST_GND | TestPoint_Pad_D1.0mm | PCB feature / no install | Not installed | N/A | BOOST_GND
U1 | TPS259814L 3V3 eFuse latch-off | Texas_RPU0010A_VQFN-HR-10_2x2mm_P0.5mm | SMD manufacturer-assembled | JLCPCB | CUSTOMER_SUPPLIED_OR_VERIFY_LCSC | TPS259814L, exact orderable package/land pattern must be verified
U2 | TPS26631RGE 5V eFuse | Texas_RGE0024H_VQFN-24-1EP_4x4mm_P0.5mm_EP2.7x2.7mm_ThermalVias | SMD manufacturer-assembled | JLCPCB | CUSTOMER_SUPPLIED_OR_VERIFY_LCSC | TPS26631RGE, exact JLC/LCSC availability must be verified
U3 | TPS26631RGE 12V eFuse | Texas_RGE0024H_VQFN-24-1EP_4x4mm_P0.5mm_EP2.7x2.7mm_ThermalVias | SMD manufacturer-assembled | JLCPCB | CUSTOMER_SUPPLIED_OR_VERIFY_LCSC | TPS26631RGE, exact JLC/LCSC availability must be verified
U4 | TPS26631RGE 16V8 eFuse | Texas_RGE0024H_VQFN-24-1EP_4x4mm_P0.5mm_EP2.7x2.7mm_ThermalVias | SMD manufacturer-assembled | JLCPCB | CUSTOMER_SUPPLIED_OR_VERIFY_LCSC | TPS26631RGE, exact JLC/LCSC availability must be verified
U5 | INA260 3V3 module | Adafruit_INA260_4226_Module | Manual/serviceable | Install manually after PCBA | N/A | INA260 3V3 module
U6 | INA260 5V module | Adafruit_INA260_4226_Module | Manual/serviceable | Install manually after PCBA | N/A | INA260 5V module
U7 | INA260 12V module | Adafruit_INA260_4226_Module | Manual/serviceable | Install manually after PCBA | N/A | INA260 12V module
U8 | INA260 16V8 module | Adafruit_INA260_4226_Module | Manual/serviceable | Install manually after PCBA | N/A | INA260 16V8 module
U9 | Boost 12V to 16.8V module 60x42 VERIFIED | Boost_Module_60x42_VERIFIED | Manual/serviceable | Install manually after PCBA | N/A | Boost 12V to 16.8V module 60x42 VERIFIED

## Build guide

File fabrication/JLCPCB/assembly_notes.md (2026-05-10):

# Assembly Notes

Status: ready for JLCPCB fabrication output review.

## JLCPCB/manufacturer assembled SMD

- U1 TPS259814L eFuse.
- U2-U4 TPS26631RGE eFuses.
- Q1-Q5 2N7002 SOT-23 MOSFETs.
- R1-R34.
- C1-C8.

All SMD parts are on the top side in the current placement. The CPL rotations are exported directly from KiCad and must be checked in the JLCPCB placement preview before order.

## Manual / serviceable installation

- A1 Arduino Nano on headers/socket.
- U5-U8 Adafruit INA260 Product 4226 breakout modules on headers.
- U9 verified 60 mm x 42 mm boost converter module.
- J1/J2 ATX screw terminal inputs.
- J3 ATX external switch terminal.
- J4 dedicated rail output terminal.
- JH1/JH2 EPS/header connectors.
- SW1-SW4 through-hole reset buttons unless a later decision is made to have them factory assembled.

## Important checks

- DRC currently has 0 violations and 0 unconnected items after routing and zone fill.
- High-current rails have rail-specific copper zones plus existing routed connectivity; short neck-downs remain at fine-pitch eFuse pins and module/header pads.
- LCSC/JLCPCB part numbers are marked customer-supplied/select-LCSC and must be selected/verified before PCBA order.
- U1 package/land pattern must be verified against the exact TPS259814L orderable part.
- No KiCad DRC or unconnected-net blockers remain.
- Final external JLCPCB/JLCDFM preview and LCSC/customer-supplied part selection still need human review before purchase.

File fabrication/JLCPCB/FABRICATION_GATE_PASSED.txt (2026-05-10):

KiCad DRC passed with 0 violations and 0 unconnected items before Gerber/drill generation.
Still perform JLCPCB/JLCDFM preview and BOM/CPL/LCSC part review before purchase.

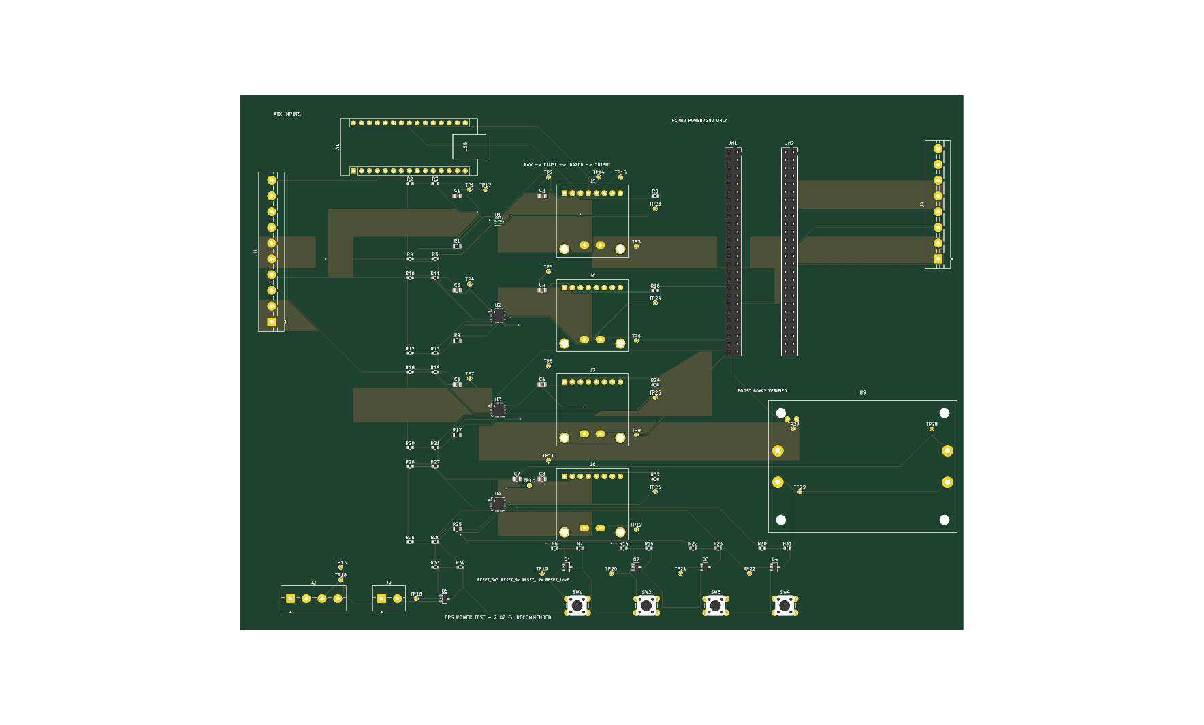
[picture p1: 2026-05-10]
fabrication/JLCPCB/preview/placement_top_3d.png

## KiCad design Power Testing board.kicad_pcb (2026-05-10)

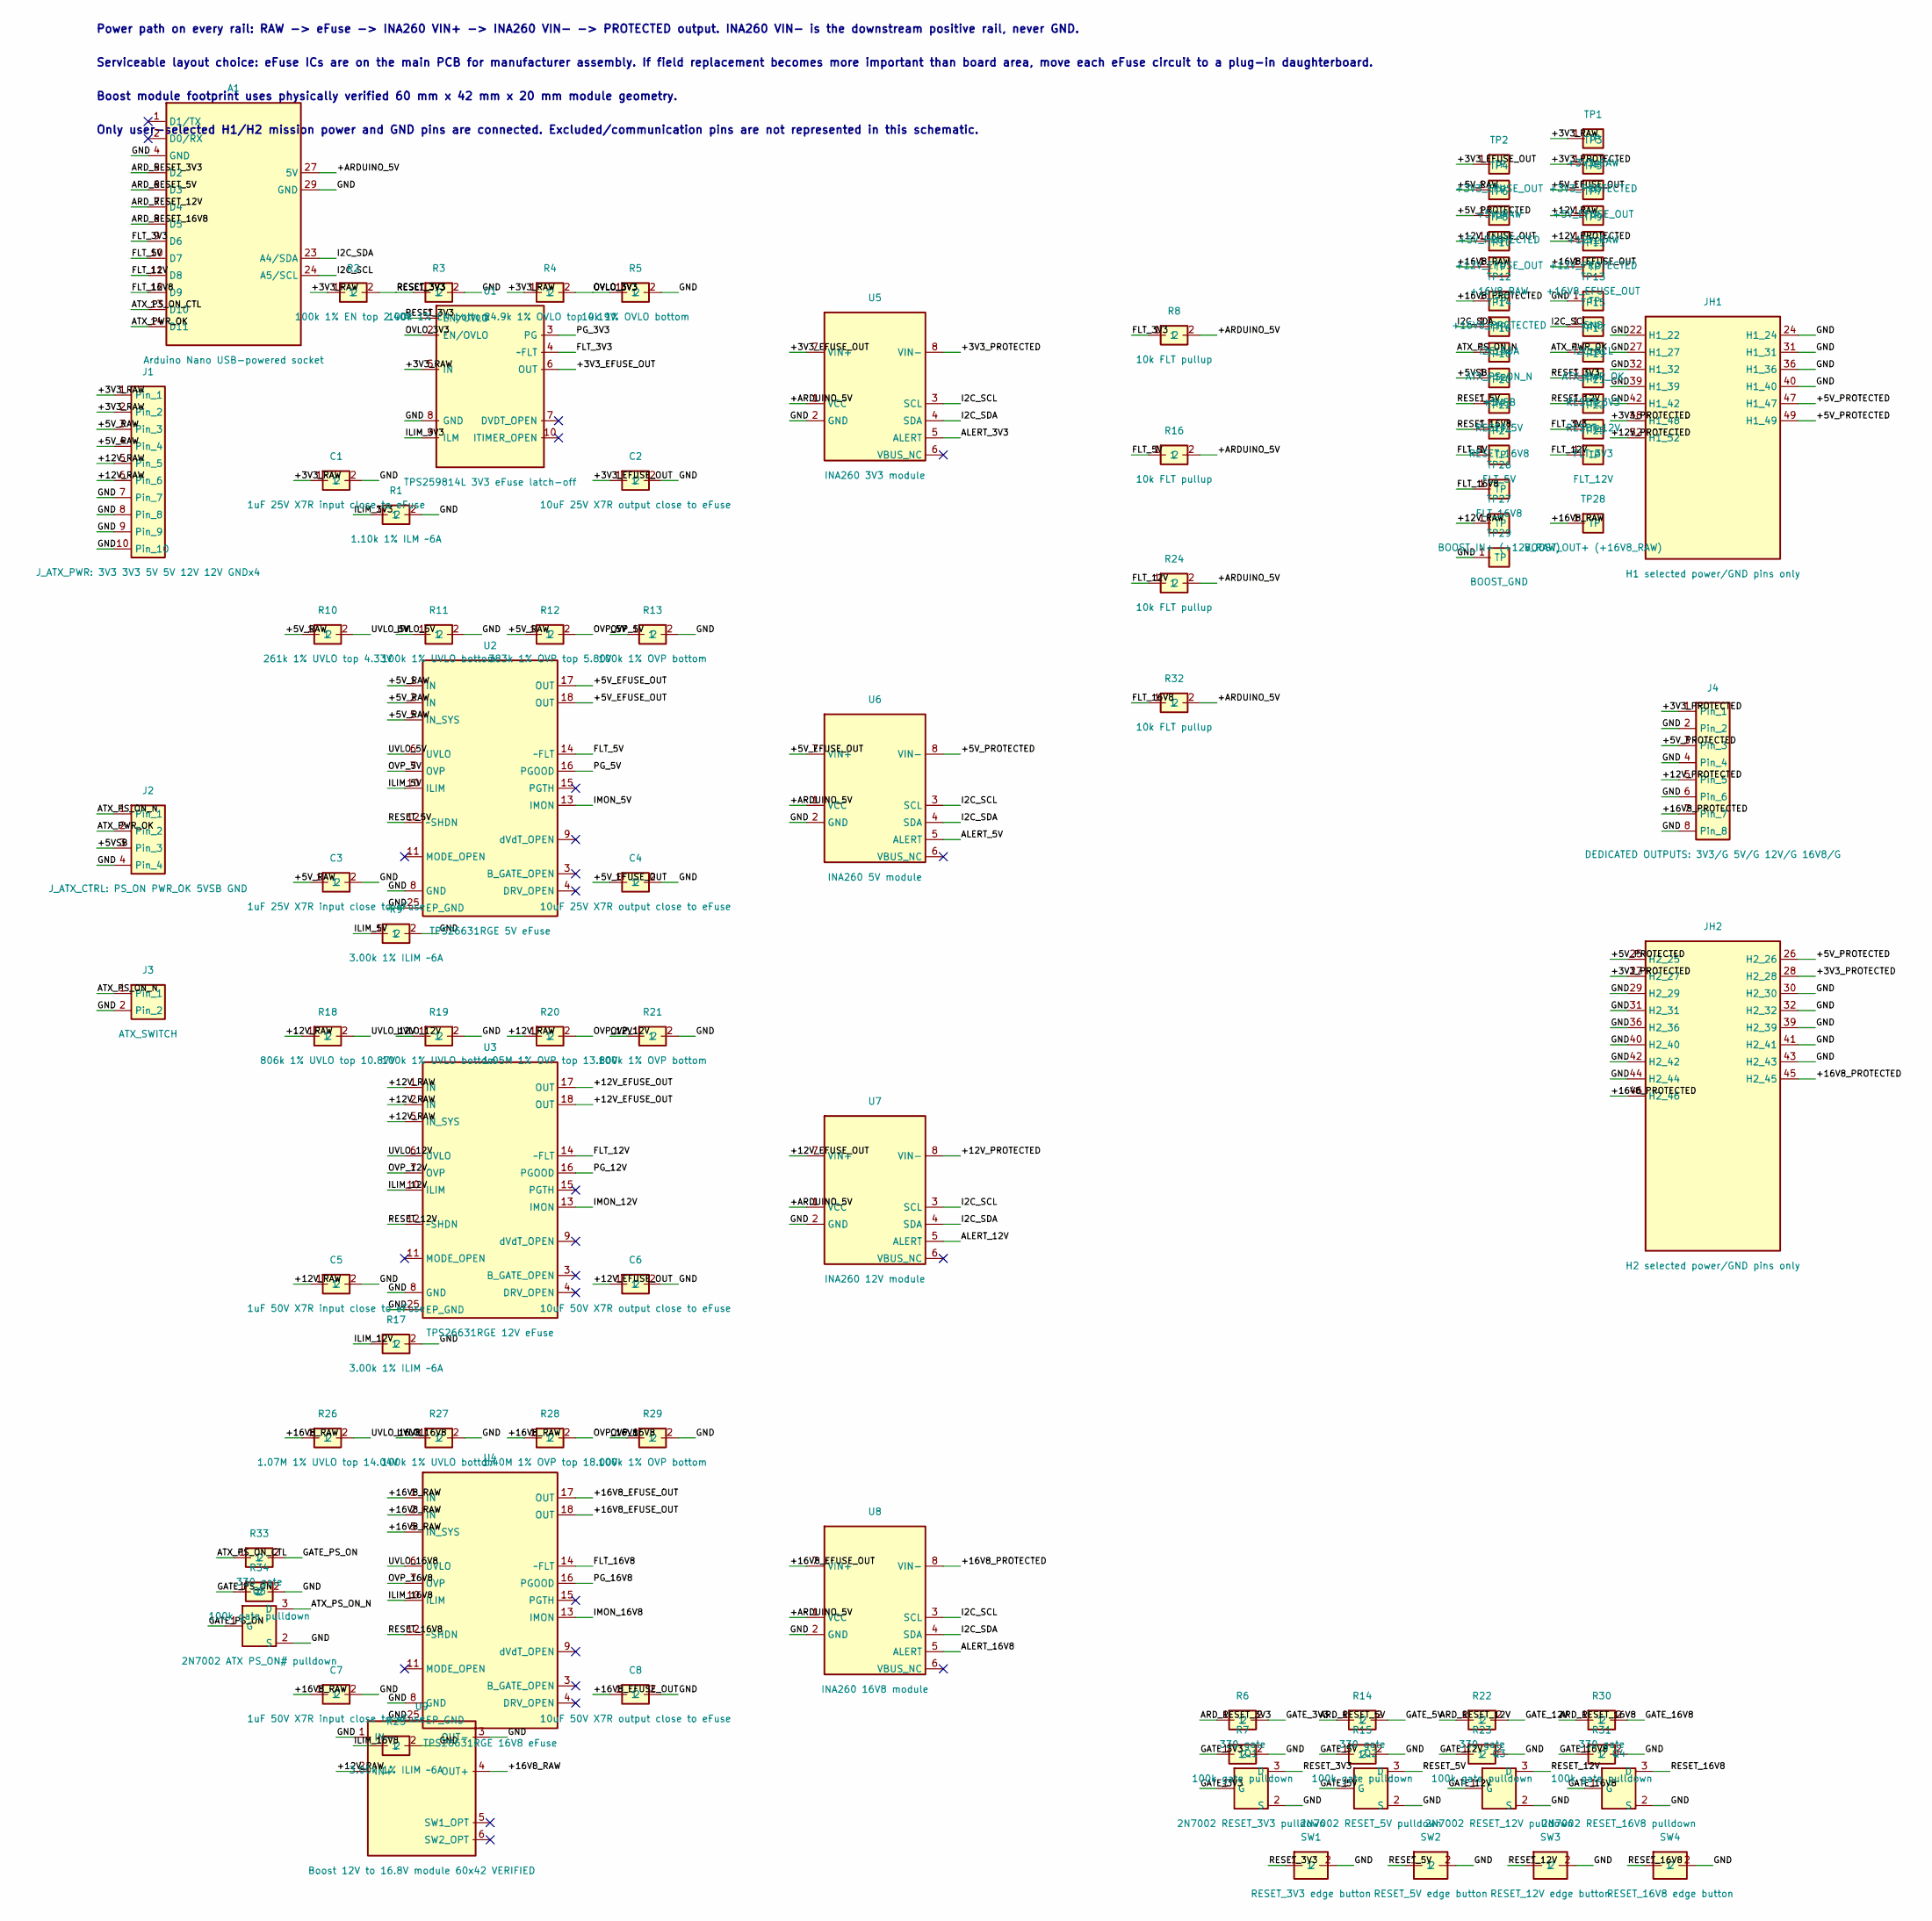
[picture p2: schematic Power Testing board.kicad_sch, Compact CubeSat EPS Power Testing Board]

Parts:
A1: Arduino Nano USB-powered socket; Arduino_Nano
C1, C3: 1uF 25V X7R input close to eFuse; C_0805_2012Metric
C2, C4: 10uF 25V X7R output close to eFuse; C_0805_2012Metric
C5, C7: 1uF 50V X7R input close to eFuse; C_0805_2012Metric
C6, C8: 10uF 50V X7R output close to eFuse; C_0805_2012Metric
J1: J_ATX_PWR: 3V3 3V3 5V 5V 12V 12V GNDx4; TerminalBlock_MaiXu_MX126-5.0-10P_1x10_P5.00mm
J2: J_ATX_CTRL: PS_ON PWR_OK 5VSB GND; TerminalBlock_MaiXu_MX126-5.0-04P_1x04_P5.00mm
J3: ATX_SWITCH; TerminalBlock_MaiXu_MX126-5.0-02P_1x02_P5.00mm
J4: DEDICATED OUTPUTS: 3V3/G 5V/G 12V/G 16V8/G; TerminalBlock_MaiXu_MX126-5.0-08P_1x08_P5.00mm
JH1: H1 selected power/GND pins only; PinSocket_2x26_P2.54mm_Vertical
JH2: H2 selected power/GND pins only; PinSocket_2x26_P2.54mm_Vertical
Q1: 2N7002 RESET_3V3 pulldown; SOT-23
Q2: 2N7002 RESET_5V pulldown; SOT-23
Q3: 2N7002 RESET_12V pulldown; SOT-23
Q4: 2N7002 RESET_16V8 pulldown; SOT-23
Q5: 2N7002 ATX PS_ON# pulldown; SOT-23
R1: 1.10k 1% ILM ~6A; R_0805_2012Metric
R2: 100k 1% EN top 2.40V; R_0603_1608Metric
R3: 100k 1% EN bottom; R_0603_1608Metric
R4: 24.9k 1% OVLO top 4.19V; R_0603_1608Metric
R5: 10k 1% OVLO bottom; R_0603_1608Metric
R6, R14, R22, R30, R33: 330 gate; R_0603_1608Metric
R7, R15, R23, R31, R34: 100k gate pulldown; R_0603_1608Metric
R8, R16, R24, R32: 10k FLT pullup; R_0603_1608Metric
R9, R17, R25: 3.00k 1% ILIM ~6A; R_0805_2012Metric
R10: 261k 1% UVLO top 4.33V; R_0603_1608Metric
R11, R19, R27: 100k 1% UVLO bottom; R_0603_1608Metric
R12: 383k 1% OVP top 5.80V; R_0603_1608Metric
R13, R21, R29: 100k 1% OVP bottom; R_0603_1608Metric
R18: 806k 1% UVLO top 10.87V; R_0603_1608Metric
R20: 1.05M 1% OVP top 13.80V; R_0603_1608Metric
R26: 1.07M 1% UVLO top 14.04V; R_0603_1608Metric
R28: 1.40M 1% OVP top 18.00V; R_0603_1608Metric
SW1: RESET_3V3 edge button; SW_PUSH_6mm
SW2: RESET_5V edge button; SW_PUSH_6mm
SW3: RESET_12V edge button; SW_PUSH_6mm
SW4: RESET_16V8 edge button; SW_PUSH_6mm
TP1: +3V3_RAW; TestPoint_Pad_D1.0mm
TP2: +3V3_EFUSE_OUT; TestPoint_Pad_D1.0mm
TP3: +3V3_PROTECTED; TestPoint_Pad_D1.0mm
TP4: +5V_RAW; TestPoint_Pad_D1.0mm
TP5: +5V_EFUSE_OUT; TestPoint_Pad_D1.0mm
TP6: +5V_PROTECTED; TestPoint_Pad_D1.0mm
TP7: +12V_RAW; TestPoint_Pad_D1.0mm
TP8: +12V_EFUSE_OUT; TestPoint_Pad_D1.0mm
TP9: +12V_PROTECTED; TestPoint_Pad_D1.0mm
TP10: +16V8_RAW; TestPoint_Pad_D1.0mm
TP11: +16V8_EFUSE_OUT; TestPoint_Pad_D1.0mm
TP12: +16V8_PROTECTED; TestPoint_Pad_D1.0mm
TP13: GND; TestPoint_Pad_D1.0mm
TP14: I2C_SDA; TestPoint_Pad_D1.0mm
TP15: I2C_SCL; TestPoint_Pad_D1.0mm
TP16: ATX_PS_ON_N; TestPoint_Pad_D1.0mm
TP17: ATX_PWR_OK; TestPoint_Pad_D1.0mm
TP18: +5VSB; TestPoint_Pad_D1.0mm
TP19: RESET_3V3; TestPoint_Pad_D1.0mm
TP20: RESET_5V; TestPoint_Pad_D1.0mm
TP21: RESET_12V; TestPoint_Pad_D1.0mm
TP22: RESET_16V8; TestPoint_Pad_D1.0mm
TP23: FLT_3V3; TestPoint_Pad_D1.0mm
TP24: FLT_5V; TestPoint_Pad_D1.0mm
TP25: FLT_12V; TestPoint_Pad_D1.0mm
TP26: FLT_16V8; TestPoint_Pad_D1.0mm
TP27: BOOST_IN+ (+12V_RAW); TestPoint_Pad_D1.0mm
TP28: BOOST_OUT+ (+16V8_RAW); TestPoint_Pad_D1.0mm
TP29: BOOST_GND; TestPoint_Pad_D1.0mm
U1: TPS259814L 3V3 eFuse latch-off; Texas_RPU0010A_VQFN-HR-10_2x2mm_P0.5mm
U2: TPS26631RGE 5V eFuse; Texas_RGE0024H_VQFN-24-1EP_4x4mm_P0.5mm_EP2.7x2.7mm_Thermal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
U3: TPS26631RGE 12V eFuse; Texas_RGE0024H_VQFN-24-1EP_4x4mm_P0.5mm_EP2.7x2.7mm_Thermal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
U4: TPS26631RGE 16V8 eFuse; Texas_RGE0024H_VQFN-24-1EP_4x4mm_P0.5mm_EP2.7x2.7mm_Thermal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
U5: INA260 3V3 module; Adafruit_INA260_4226_Module
U6: INA260 5V module; Adafruit_INA260_4226_Module
U7: INA260 12V module; Adafruit_INA260_4226_Module
U8: INA260 16V8 module; Adafruit_INA260_4226_Module
U9: Boost 12V to 16.8V module 60x42 VERIFIED; Boost_Module_60x42_VERIFIED

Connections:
+3V3_EFUSE_OUT: C2.1, TP2.1, U1.6 (OUT), U5.7 (VIN+)
+3V3_PROTECTED: J4.1, JH1.48 (H1_48), JH2.27 (H2_27), JH2.28 (H2_28), TP3.1, U5.8 (VIN-)
+3V3_RAW: C1.1, J1.1, J1.2, R2.1, R4.1, TP1.1, U1.5 (IN)
+5VSB: J2.3, TP18.1
+5V_EFUSE_OUT: C4.1, TP5.1, U2.17 (OUT), U2.18 (OUT), U6.7 (VIN+)
+5V_PROTECTED: J4.3, JH1.47 (H1_47), JH1.49 (H1_49), JH2.25 (H2_25), JH2.26 (H2_26), TP6.1, U6.8 (VIN-)
+5V_RAW: C3.1, J1.3, J1.4, R10.1, R12.1, TP4.1, U2.1 (IN), U2.2 (IN), U2.5 (IN_SYS)
+12V_EFUSE_OUT: C6.1, TP8.1, U3.17 (OUT), U3.18 (OUT), U7.7 (VIN+)
+12V_PROTECTED: J4.5, JH1.52 (H1_52), TP9.1, U7.8 (VIN-)
+12V_RAW: C5.1, J1.5, J1.6, R18.1, R20.1, TP7.1, TP27.1, U3.1 (IN), U3.2 (IN), U3.5 (IN_SYS), U9.2 (IN+)
+16V8_EFUSE_OUT: C8.1, TP11.1, U4.17 (OUT), U4.18 (OUT), U8.7 (VIN+)
+16V8_PROTECTED: J4.7, JH2.45 (H2_45), JH2.46 (H2_46), TP12.1, U8.8 (VIN-)
+16V8_RAW: C7.1, R26.1, R28.1, TP10.1, TP28.1, U4.1 (IN), U4.2 (IN), U4.5 (IN_SYS), U9.4 (OUT+)
+ARDUINO_5V: A1.27 (5V), R8.2, R16.2, R24.2, R32.2, U5.1 (VCC), U6.1 (VCC), U7.1 (VCC), U8.1 (VCC)
ALERT_3V3: U5.5 (ALERT)
ALERT_5V: U6.5 (ALERT)
ALERT_12V: U7.5 (ALERT)
ALERT_16V8: U8.5 (ALERT)
ARD_RESET_3V3: A1.5 (D2), R6.1
ARD_RESET_5V: A1.6 (D3), R14.1
ARD_RESET_12V: A1.7 (D4), R22.1
ARD_RESET_16V8: A1.8 (D5), R30.1
ATX_PS_ON_CTL: A1.13 (D10), R33.1
ATX_PS_ON_N: J2.1, J3.1, Q5.3 (D), TP16.1
ATX_PWR_OK: A1.14 (D11), J2.2, TP17.1
FLT_3V3: A1.9 (D6), R8.1, TP23.1, U1.4 (~FLT)
FLT_5V: A1.10 (D7), R16.1, TP24.1, U2.14 (~FLT)
FLT_12V: A1.11 (D8), R24.1, TP25.1, U3.14 (~FLT)
FLT_16V8: A1.12 (D9), R32.1, TP26.1, U4.14 (~FLT)
GATE_3V3: Q1.1 (G), R6.2, R7.1
GATE_5V: Q2.1 (G), R14.2, R15.1
GATE_12V: Q3.1 (G), R22.2, R23.1
GATE_16V8: Q4.1 (G), R30.2, R31.1
GATE_PS_ON: Q5.1 (G), R33.2, R34.1
GND: A1.4 (GND), A1.29 (GND), C1.2, C2.2, C3.2, C4.2, C5.2, C6.2, C7.2, C8.2, J1.7, J1.8, J1.9, J1.10, J2.4, J3.2, J4.2, J4.4, J4.6, J4.8, JH1.22 (H1_22), JH1.24 (H1_24), JH1.27 (H1_27), JH1.31 (H1_31), JH1.32 (H1_32), JH1.36 (H1_36), JH1.39 (H1_39), JH1.40 (H1_40), JH1.42 (H1_42), JH2.29 (H2_29), JH2.30 (H2_30), JH2.31 (H2_31), JH2.32 (H2_32), JH2.36 (H2_36), JH2.39 (H2_39), JH2.40 (H2_40), JH2.41 (H2_41), JH2.42 (H2_42), JH2.43 (H2_43), JH2.44 (H2_44), Q1.2 (S), Q2.2 (S), Q3.2 (S), Q4.2 (S), Q5.2 (S), R1.2, R3.2, R5.2, R7.2, R9.2, R11.2, R13.2, R15.2, R17.2, R19.2, R21.2, R23.2, R25.2, R27.2, R29.2, R31.2, R34.2, SW1.2, SW2.2, SW3.2, SW4.2, TP13.1, TP29.1, U1.8 (GND), U2.8 (GND), U2.25 (EP_GND), U3.8 (GND), U3.25 (EP_GND), U4.8 (GND), U4.25 (EP_GND), U5.2 (GND), U6.2 (GND), U7.2 (GND), U8.2 (GND), U9.1 (IN-), U9.3 (OUT-)
I2C_SCL: A1.24 (A5/SCL), TP15.1, U5.3 (SCL), U6.3 (SCL), U7.3 (SCL), U8.3 (SCL)
I2C_SDA: A1.23 (A4/SDA), TP14.1, U5.4 (SDA), U6.4 (SDA), U7.4 (SDA), U8.4 (SDA)
ILIM_3V3: R1.1, U1.9 (ILM)
ILIM_5V: R9.1, U2.10 (ILIM)
ILIM_12V: R17.1, U3.10 (ILIM)
ILIM_16V8: R25.1, U4.10 (ILIM)
IMON_5V: U2.13 (IMON)
IMON_12V: U3.13 (IMON)
IMON_16V8: U4.13 (IMON)
OVLO_3V3: R4.2, R5.1, U1.2 (EN/OVLO)
OVP_5V: R12.2, R13.1, U2.7 (OVP)
OVP_12V: R20.2, R21.1, U3.7 (OVP)
OVP_16V8: R28.2, R29.1, U4.7 (OVP)
PG_3V3: U1.3 (PG)
PG_5V: U2.16 (PGOOD)
PG_12V: U3.16 (PGOOD)
PG_16V8: U4.16 (PGOOD)
RESET_3V3: Q1.3 (D), R2.2, R3.1, SW1.1, TP19.1, U1.1 (EN/UVLO)
RESET_5V: Q2.3 (D), SW2.1, TP20.1, U2.12 (~SHDN)
RESET_12V: Q3.3 (D), SW3.1, TP21.1, U3.12 (~SHDN)
RESET_16V8: Q4.3 (D), SW4.1, TP22.1, U4.12 (~SHDN)
UVLO_5V: R10.2, R11.1, U2.6 (UVLO)
UVLO_12V: R18.2, R19.1, U3.6 (UVLO)
UVLO_16V8: R26.2, R27.1, U4.6 (UVLO)

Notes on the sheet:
Power path on every rail: RAW -> eFuse -> INA260 VIN+ -> INA260 VIN- -> PROTECTED output. INA260 VIN- is the downstream positive rail, never GND.
Serviceable layout choice: eFuse ICs are on the main PCB for manufacturer assembly. If field replacement becomes more important than board area, move each eFuse circuit to a plug-in daughterboard.
Boost module footprint uses physically verified 60 mm x 42 mm x 20 mm module geometry.
Only user-selected H1/H2 mission power and GND pins are connected. Excluded/communication pins are not represented in this schematic.

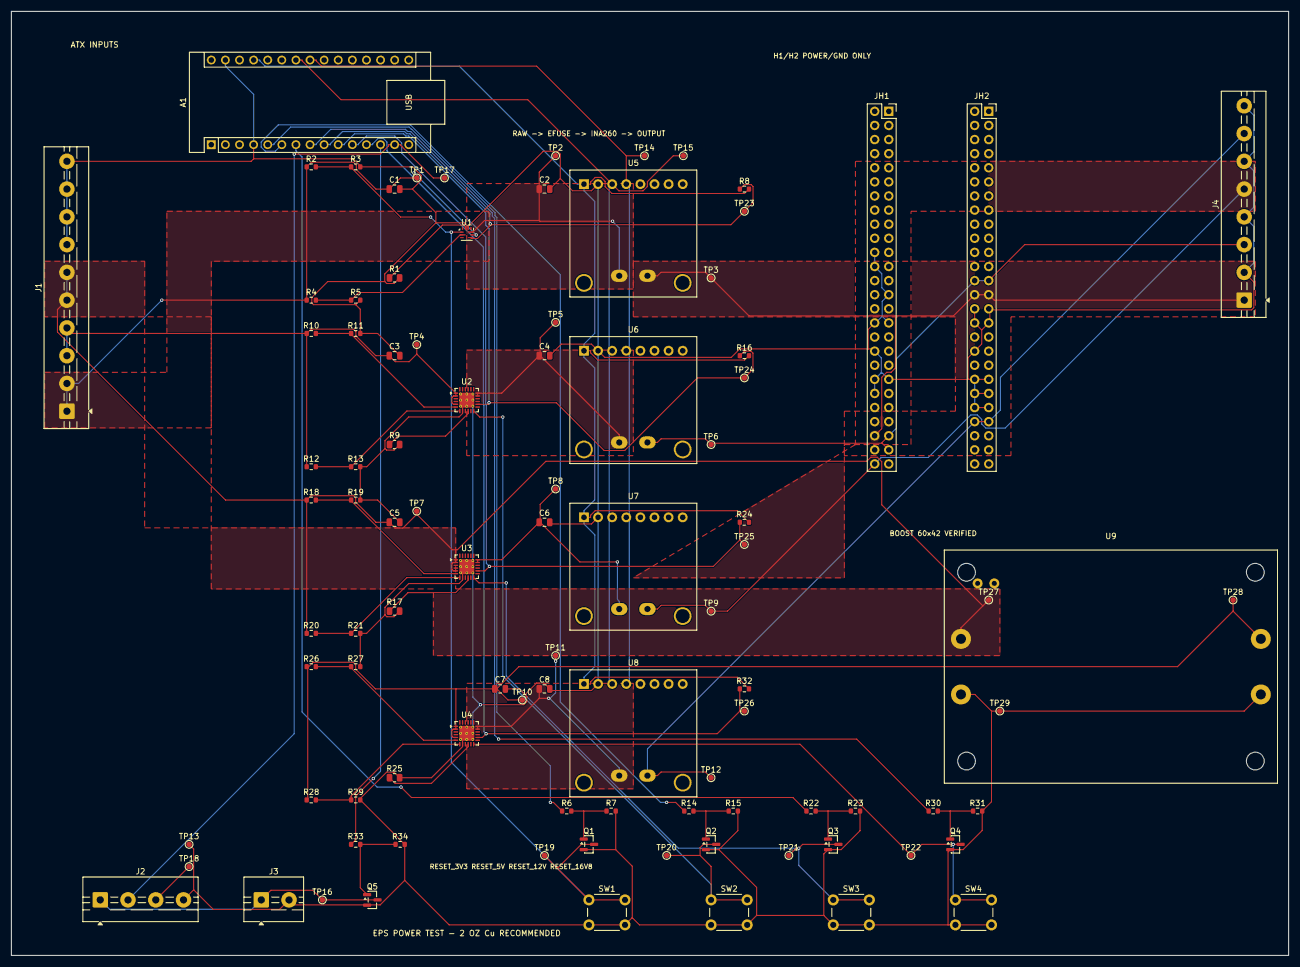
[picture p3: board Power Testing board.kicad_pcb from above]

Board: 2 copper layers, 230.0 x 170.0 mm, 96 parts (0 on the bottom side), 48 nets.

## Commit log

2026-04-16 testing res
    [Power Testing board.kicad_sch]
2026-04-25 ina260 starting connects
    [Power Testing board.kicad_sch]
2026-04-25 New pages
    [Headers.kicad_sch, Power Testing board.kicad_sch, untitled.kicad_sch]
2026-04-30 buck/boost eschematic
    [Power Testing board.kicad_pcb, boost.kicad_sch, untitled.kicad_sch]
2026-04-30 boost/buck test
2026-04-30 Revert "boost/buck test"
    This reverts commit 996bf898ef0943a081c312dd8d057b7a6ef081b4.
2026-04-30 Reapply "boost/buck test"
    This reverts commit 69a8d86dd8fea79acaaa3a28afc8224535b4a10d.
2026-05-10 GPT progress
    [Power Testing board.kicad_pcb, Power Testing board.kicad_sch]
2026-05-10 chat gpt pt.2
    [BOM_MASTER.csv, BOM_SMD_JLCPCB.csv, Power Testing board.kicad_pcb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]
